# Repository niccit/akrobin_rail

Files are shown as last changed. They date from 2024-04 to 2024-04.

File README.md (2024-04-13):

# Two Bin Expandable Akrobins Hangers

## The What

These are small hangers for your Akrobins that you can attach anywhere. Each hanger will hold two Akrobins.

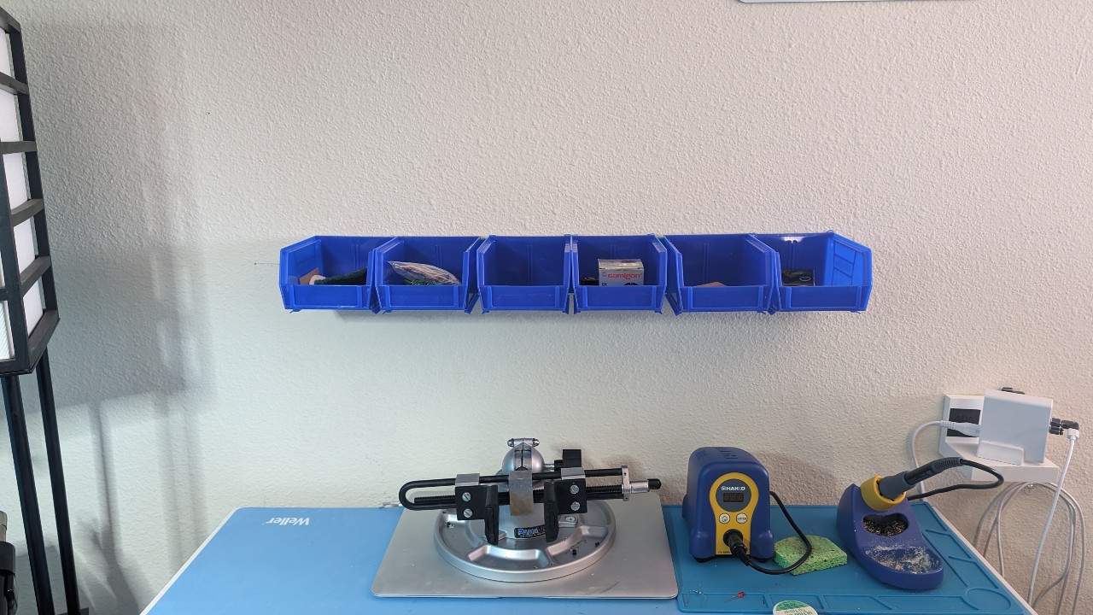
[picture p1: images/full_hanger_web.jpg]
Rail Full


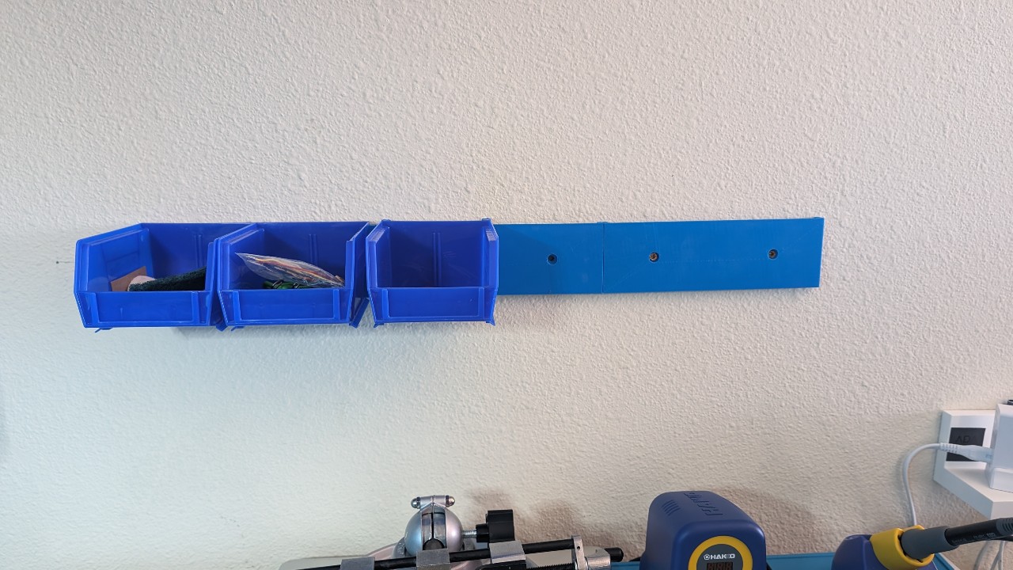
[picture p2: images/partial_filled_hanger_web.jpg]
Rail Partial


## The Why

To start off, I don't have a ton of bins - yet. And since these are being used in my office/workshop I didn't want to
get one of the industrial-sized ones you see for purchase in most stores.

With this design, I can add on new rails when and where I need.

## The Design

It's a basic design. The hanger rail can hold two bins. The bins can be removed/replaced as needed. If you want to have
more than two bins hung side-by-side you can print additional hanger rails and secure them together with pins. 
Pins library provided by [tbuser](https://github.com/tbuser/pin_connectors).

The mounting holes are countersunk so that the mounting screws don't interfere with the bins when hung on the rail.
Library for the mounting holes provided by [mmalecki](https://github.com/mmalecki/catchnhole)

## The Execution

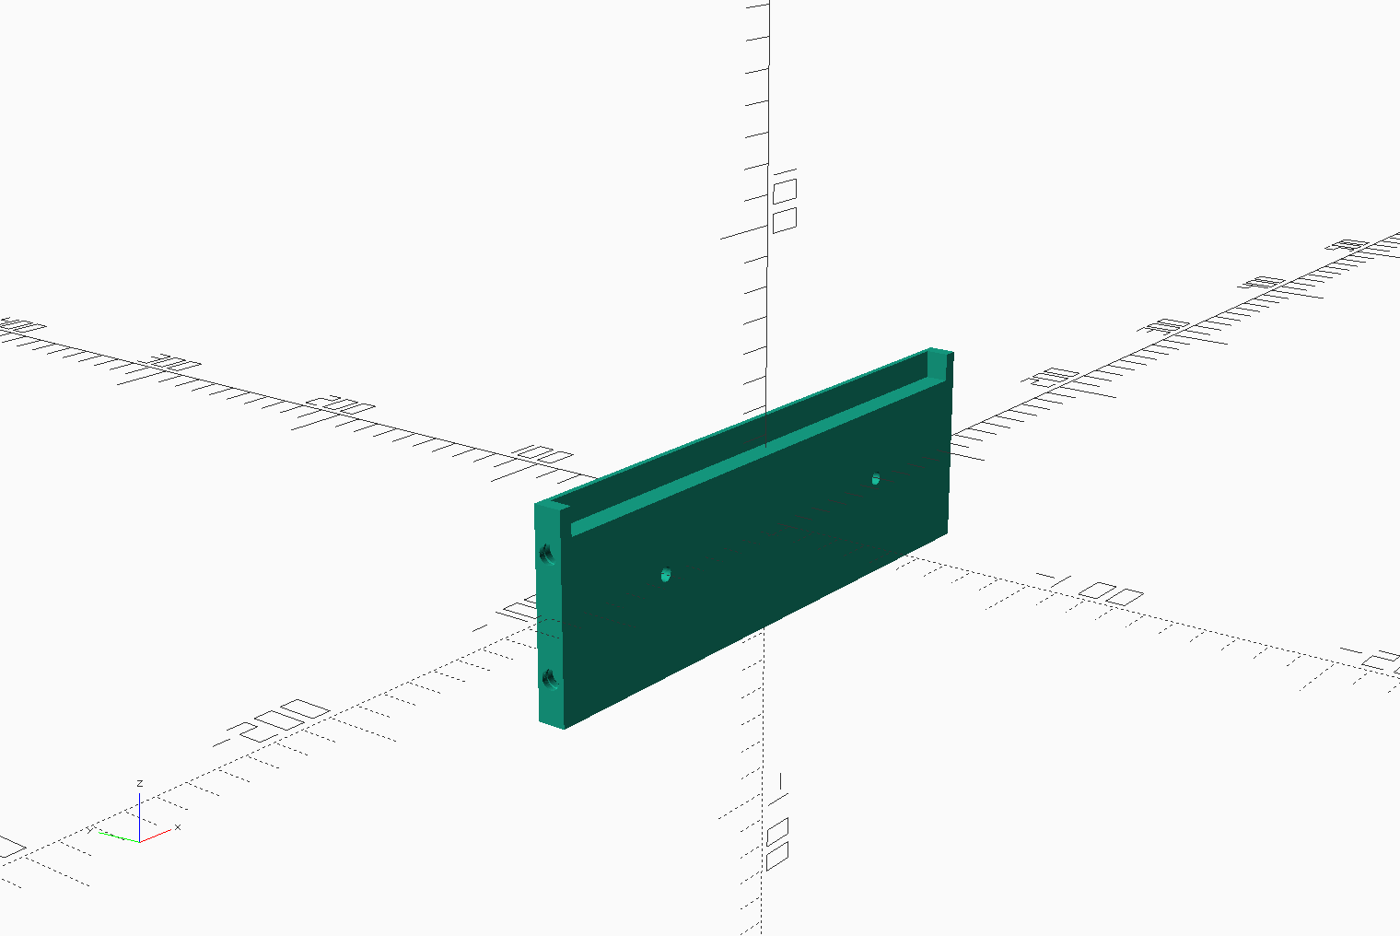
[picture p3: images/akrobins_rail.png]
OpenSCAD model


Designed in OpenSCAD with the intent to be configurable. My 3D printer
can only support up to 220mm x 200mm x 250mm print size; which is why I went with two bins per rail. You can change the
dimensions to suit your printer. 

Printed on a FlashForge Adventurer 4 using:
* PrintLife Pro PLA
* Bed Temp: 50c
* Nozzle Temp: 220c
* Supports: Yes, auto, optional - I wanted the front of the pate to look good, if I had flipped it to avoid supports it wouldn't 
have looked nice because I probably need to replace my plate :)
  * Supports Type: Line
  * Pillar Size: 1.5mm
  * Touch Platform Only
  * Space to Model (X/Y) - Slicer: 70mm 
* Raft: Optional _It's a personal decision_
* Infill: Line
* Fill Density: 10%

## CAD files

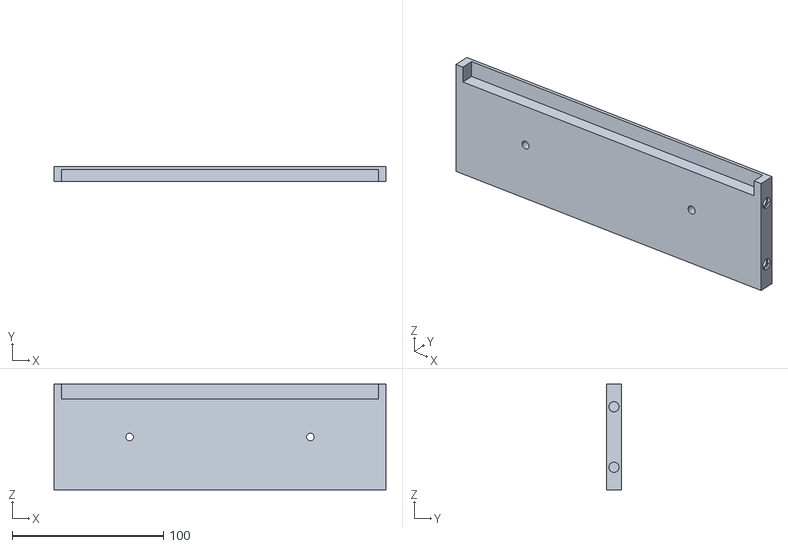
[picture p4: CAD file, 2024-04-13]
STL_files/akrobins_rail.stl
219.5 x 10.0 x 70.0

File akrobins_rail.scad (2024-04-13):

// SPDX-License-Identifier: MIT // A modularized way to hang my Akrobins. I didn't need the big metal louvered hangers available.

use <catchnhole/catchnhole.scad>;  // mmalecki - https://github.com/mmalecki/catchnhole
use <pin_connectors/pin_joints.scad>;  // tbuser - https://github.com/tbuser/pin_connectors

$fa = 1;
$fs = 0.4;

cube_l = 219.5;
cube_w = 10;
cube_h = 70;

use_mounting_holes = true;
use_connecting_holes = true;
show_all = false;
show_backplate=true;
show_pin=false;

module rail() {
    cube([(l - 10), 8, 10], center=true);
}

module backplate(l=cube_l, w=cube_w, h=cube_h, mounting_holes=use_mounting_holes) {
    difference() {
        cube([l, w, h], center = true);
        // hanger
        translate([0, -1, 30.25])
            cube([(l - 10), 8, 10], center = true);
        // mounting hole
        if (mounting_holes == true) {
            translate([(cube_l / 2 - 50), -6.75, 0])
                rotate([-90, 0, 0])
                    bolt("M5", 12, kind = "countersunk", countersink = 1);
            translate([-(cube_l / 2 - 50), -6.75, 0])
                rotate([-90, 0, 0])
                    bolt("M5", 12, kind = "countersunk", countersink = 1);
        }
        if (use_connecting_holes == true) {
            // connecting pinholes, left side
            translate([(cube_l / 2) - 5, 0, 0])
                connector_pinholes("left");
            // connecting pinholes, right side
            translate([-(cube_l / 2) + 5 , 0, 0])
                connector_pinholes("right");
        }
    }

}

module connector_pinholes(dir) {
        if (dir == "left") {
            translate([0, 0, 20])
                rotate([0, 90, 0])
                    pinhole(h=5, r=3, lh=3, lt=1, t=0.3, tight=false);
            translate([0, 0, -20])
                rotate([0, 90, 0])
                    pinhole(h=5, r=3, lh=3, lt=1, t=0.3, tight=false);
        }
        else {
            translate([0, 0, 20])
                rotate([0, -90, 0])
                    pinhole(h=5, r=3, lh=3, lt=1, t=0.3, tight=false);
            translate([0, 0, -20])
                rotate([0, -90, 0])
                    pinhole(h=5, r=3, lh=3, lt=1, t=0.3, tight=false);
        }
}

module pin() {
    pinpeg(h=10, r=3.25, lh=3, lt=1);
}




// --- Printing --- //


if (show_all == true) {
    backplate();
    rotate([0, 90, 90])
        translate([-20, -(cube_l / 2) - 0.5, -2.25])
            pin();
    rotate([0, 90, 90])
        translate([20, -(cube_l / 2) - 0.5, -2.25])
            pin();
}
else if (show_backplate == true) {
    backplate();
}
else if (show_pin == true) {  // for printing just the pin
    pin();
}

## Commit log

2024-04-05 Initial check-in
    [akrobins_rail.scad, akrobins_rail.stl]
2024-04-05 Added comment to JointSCAD import
    [akrobins_rail.scad]
2024-04-13 Finalized version of rail. Updated STL files and added new submodule, pin_connectors
    [akrobins_rail.scad, akrobins_rail.stl]
